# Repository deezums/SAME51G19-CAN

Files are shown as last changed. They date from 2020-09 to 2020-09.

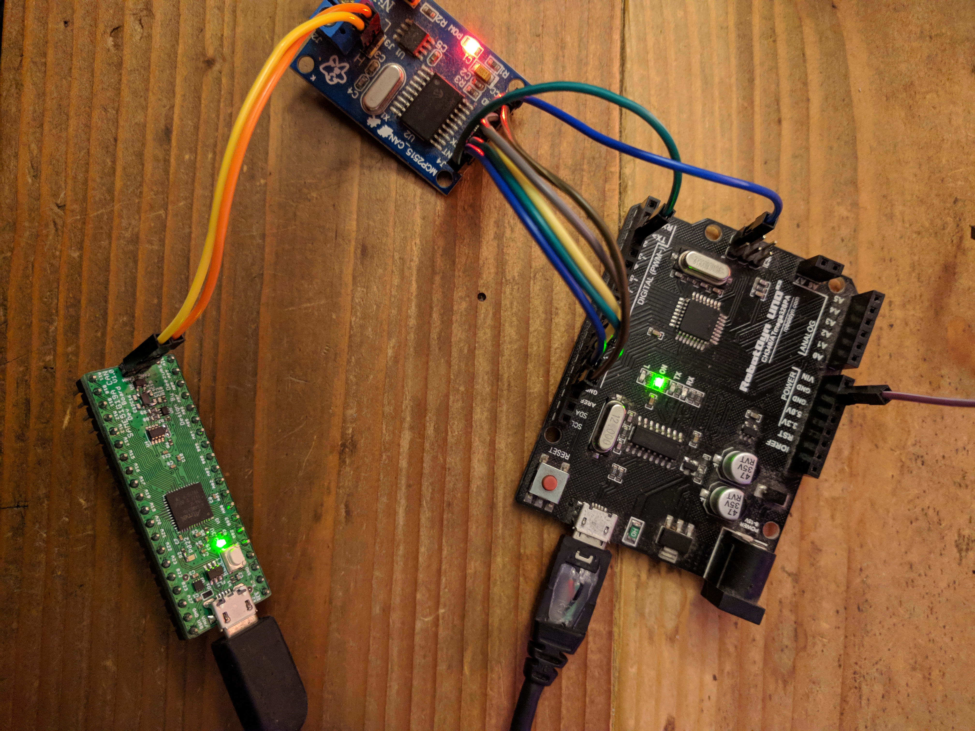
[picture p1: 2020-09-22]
extras/photos/SAME51G19A_CAN_INDEX.jpg

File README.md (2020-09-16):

# SAME51G19-CAN
Atmel ATSAME51G19A breakout board with TI TCAN33x transciever

This is version 1.0 of my ATSAME51G19A breakout board. 

Includes a 3.3V LDO, usb power, a led on PB22, reset switch, and 3V power led.

The canbus transiever contains a common mode choke, tvs array, and plenty of filter caps which can be optimally tuned to bus frequency. 

Digital split bus termiation using a mosfet array and resistors matched to rds, solder jumper allows disable, permanant pullup, or CPU control through PA21. 

Mostly 0402 components...

Tested working with atmel studio start examples and ATSAME54XPLAINED board. Hope to eventually port to Arduino with proper canbus library support.

Issues...

CMC pads should be narrowed vertically and can be horizontally compressed a fair bit.

Solder jumper pads are terrible, think too narrow and sharp. If not for 63/37 I don't think I could use them. 

TCAN33x, the extra function pins are not currently routed to CPU pins. Use TCAN332, or route the extra pins if you want to use hardware features of other variants.

Why did I make the silkscreen so small?! What pin is this!!

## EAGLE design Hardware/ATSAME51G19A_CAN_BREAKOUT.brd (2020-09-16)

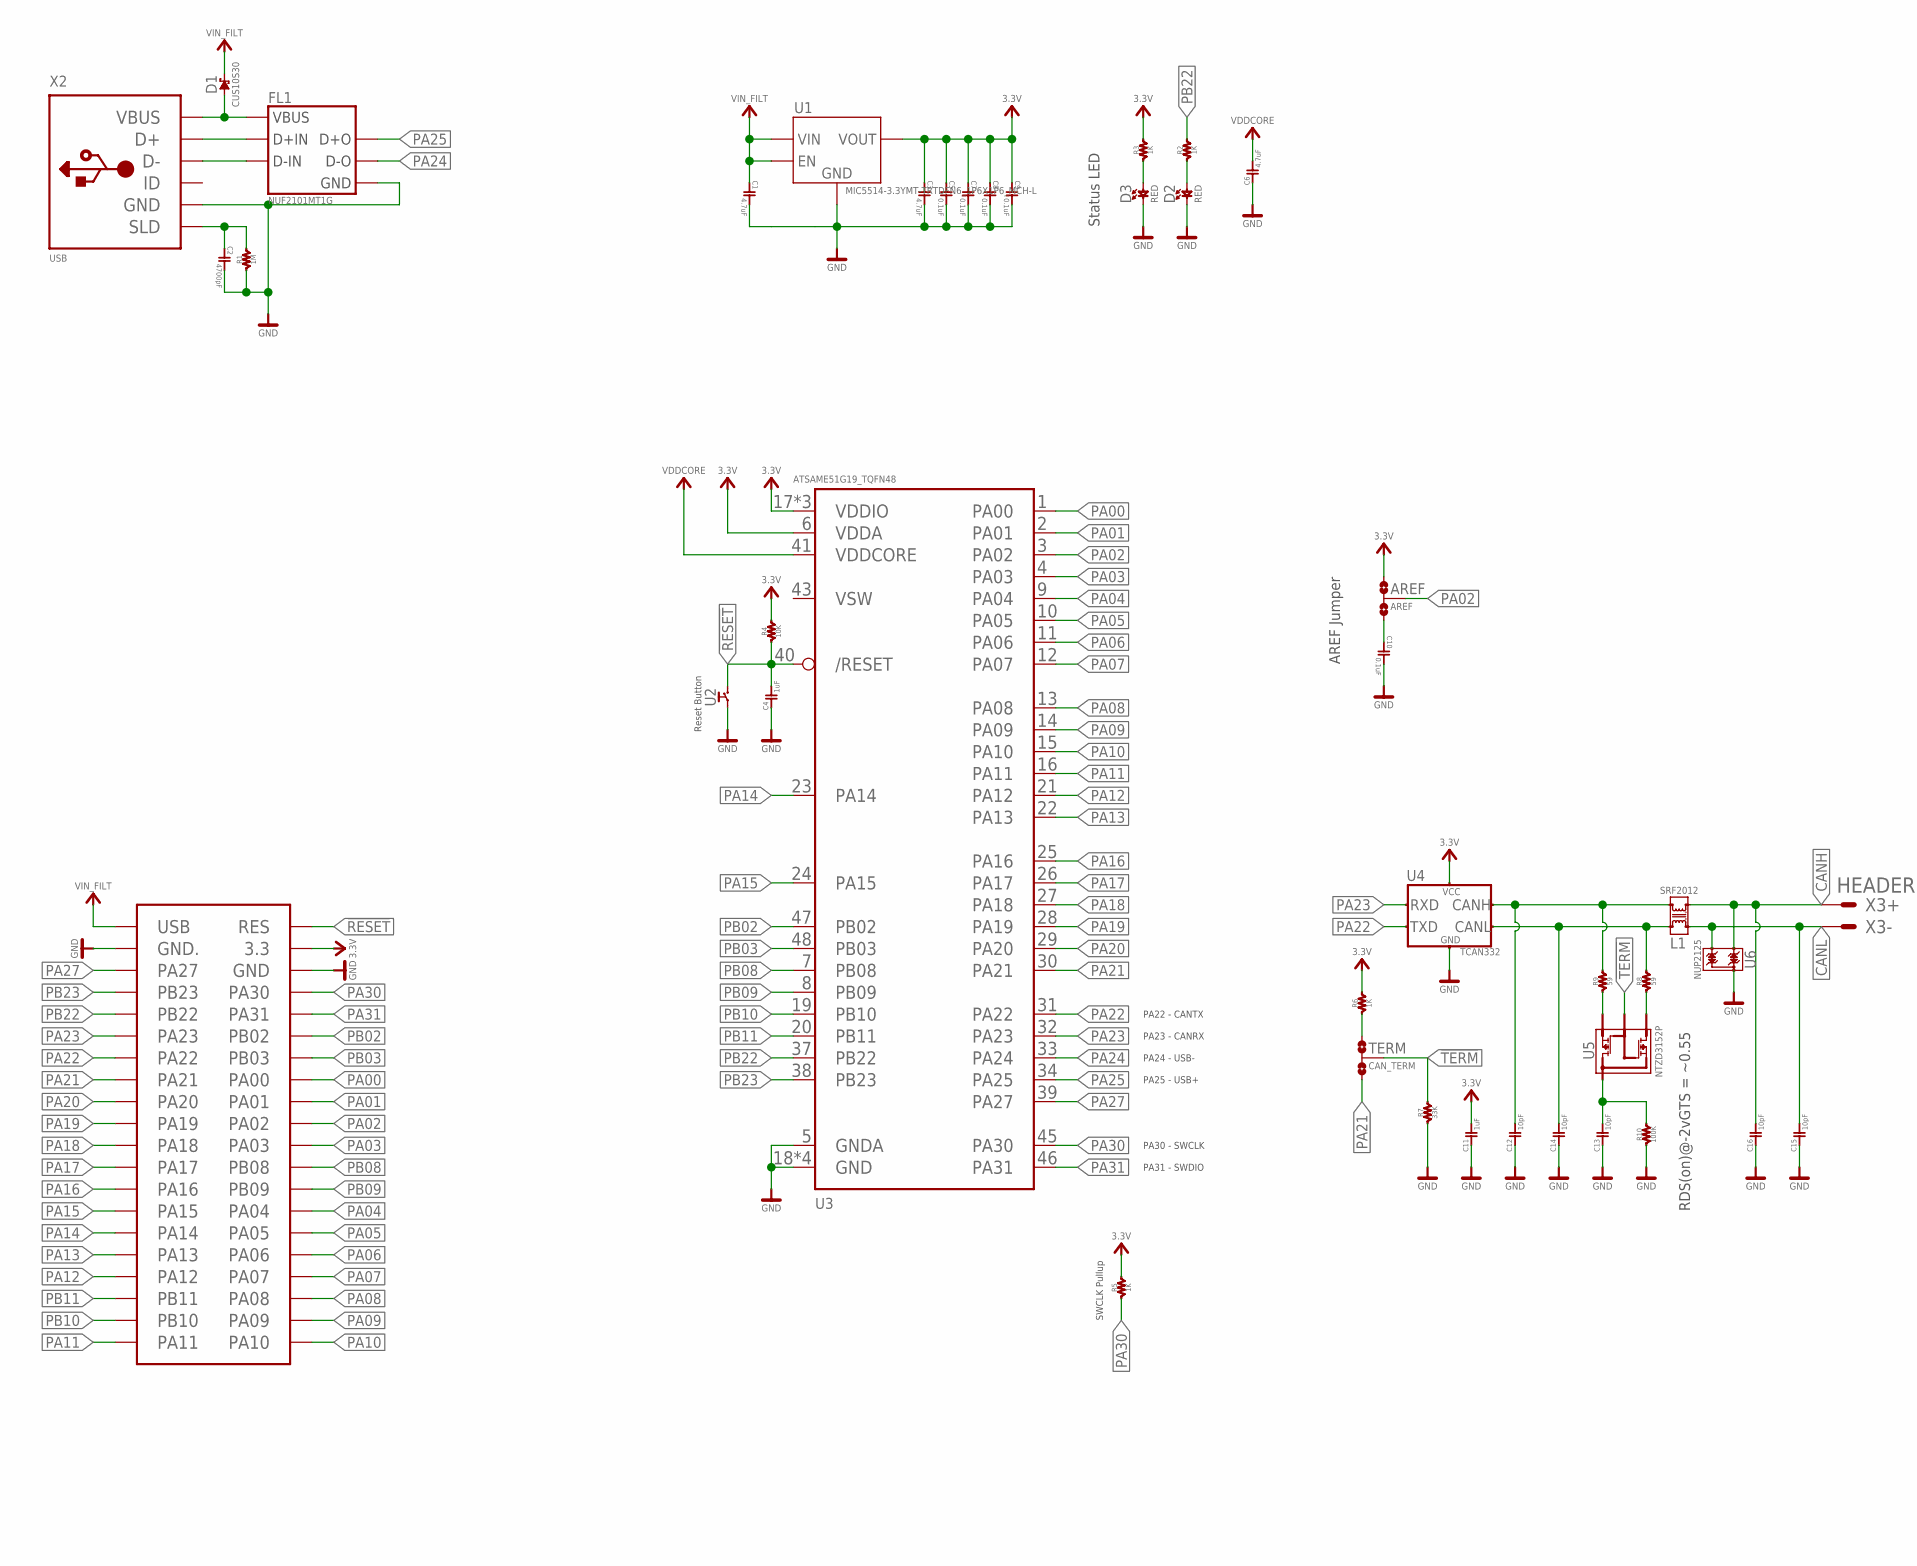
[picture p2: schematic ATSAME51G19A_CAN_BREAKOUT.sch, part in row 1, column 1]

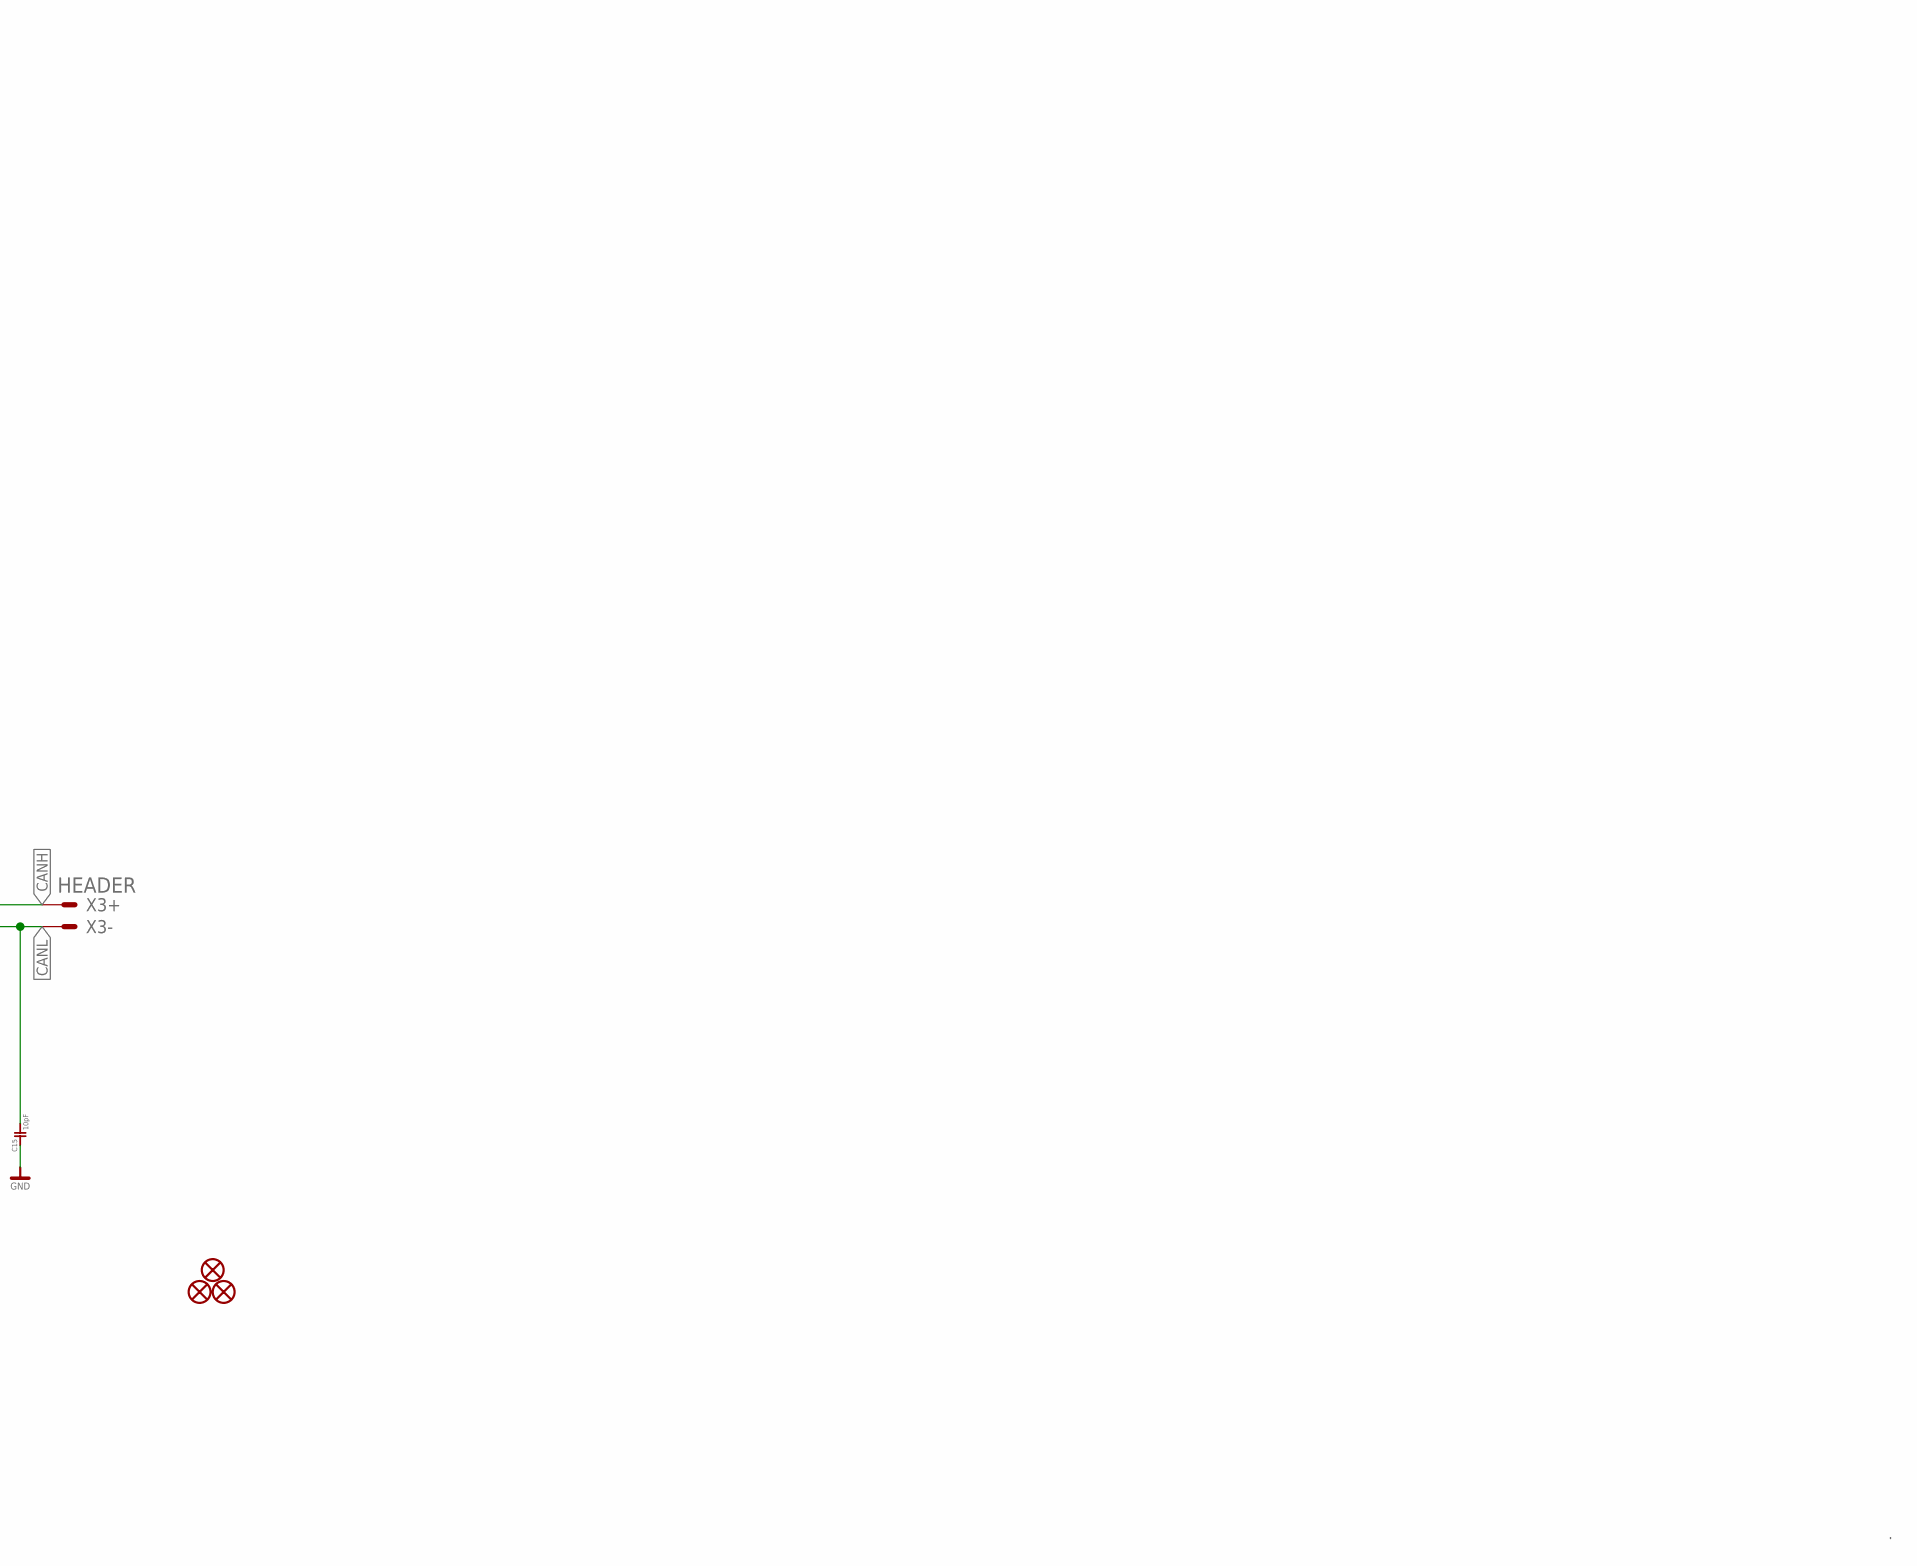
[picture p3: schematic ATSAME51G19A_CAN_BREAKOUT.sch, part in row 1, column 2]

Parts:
AREF: AREF; C0R-JMP
C1: 4.7uF; CAP0402; VOLTAGE 10V; MPN CL05A106MP8NUB8
C2: 4700pF; CAP0402; VOLTAGE 25V; MPN CC0402KRX7R8BB472
C3, C6: 4.7uF; CAP0402; VOLTAGE 6.3V; MPN GRM155R60J106ME05D
C4, C11: 1uF; CAP0402; VOLTAGE 6.3V; MPN CL05A105KQ5NNNC
C5, C7, C8, C9, C10: 0.1uF; CAP0402; VOLTAGE 6.3V; MPN CL05A105KQ5NNNC
C12, C13, C14, C15, C16: 10pF; CAP0402; VOLTAGE 50V; MPN C0402C100K5RAC7867
D1: CUS10S30; X3-WLB1608-2; MPN SDM2U30CSP-7
D2, D3: 0603 LED; LED-0603; MPN LNJ8W0C83RA
FID1, FID2, FID3: MICROBUILDER_FIDUCIAL_0.5MM
FL1: NUF2101MT1G; SOT95P275X110-6N
L1: SRF2012; SRF2012AA; MPN SRF2012-121YA
R1: 1M; RES0402; TOLERANCE 1%; MPN PFR05S-105-FNH
R2, R3: 1K; RES0402; TOLERANCE 1%; MPN CR0402-FX-1002GLF
R4: 10K; RES0402; TOLERANCE 1%; MPN CR0402-FX-1002GLF
R5, R6: 1K; RES0402; TOLERANCE 1%; MPN PFR05S-102-FNH
R7: 33K; RES0402; TOLERANCE 1%; MPN RMCF0402FT33K0
R8, R9: 59; RES0603; TOLERANCE 1%; MPN CRCW060359R0FKEAHP
R10: 100K; RES0402; TOLERANCE 1%; MPN CR0402-FX-1003GLF
TERM: CAN_TERM; C0R-JMP
U1: MIC5514-3.3YMT-TRTDFN6_1P6X1P6_MCH-L; TDFN6_1P6X1P6_MCH-L
U2: PUSH_SWITCHPTS815; SWITCH_PTS815; MPN PTS815 SJM 250 SMTR LFS
U3: ATSAME51G19_TQFN48; TQFN48_7MM; MPN ATSAME51G19A-MF
U4: TCAN332; DCN0008A; MPN TCAN332DCNR
U5: NTZD3152P; SOT-563; MPN NTZD3152PT1G
U6: NUP2125; SC70; MPN NUP2125WTT1G
X1: CONN; BOARDOUTLINE
X2: USB; 10118194
X3: HEADER; 22-23-2021

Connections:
3.3V: AREF.1, C3.1 (C1), C5.1 (C1), C7.1 (C1), C8.1 (C1), C9.1 (C1), C11.2 (C2), R3.2, R4.2, R5.2, R6.2, U1.4 (VOUT), U1.5 (VOUT), U3.6 (VDDA), U3.17 (VDDIO), U3.36 (VDDIO), U3.44 (VDDIO), U4.3 (VCC), X1.3.3
!RESET: C4.2 (C2), R4.1, U2.P$3 (2), U2.P$4 (2), U3.40 (/RESET), X1.!RES (RES)
!TERM: R7.2, TERM.2, U5.P$2 (GATE), U5.P$5 (GATE)
CANH: C16.2 (C2), L1.4, U6.1, X3.1
CANL: C15.2 (C2), L1.1, U6.2, X3.2
GND: C1.2 (C2), C2.2 (C2), C3.2 (C2), C4.1 (C1), C5.2 (C2), C6.1 (C1), C7.2 (C2), C8.2 (C2), C9.2 (C2), C10.2 (C2), C11.1 (C1), C12.1 (C1), C13.1 (C1), C14.1 (C1), C15.1 (C1), C16.1 (C1), D2.C, D3.C, FL1.2 (GND), R1.1, R7.1, R10.1, U1.6 (GND), U1.7 (GND), U2.P$1 (1), U2.P$2 (1), U3.5 (GNDA), U3.18 (GND), U3.35 (GND), U3.42 (GND), U3.THERMAL (GND), U4.2 (GND), U6.3, X1.GND, X1.GND., X2.5 (GND)
unnamed: C13.2 (C2), R10.2, U5.P$4 (DRAIN1), U5.P$6 (DRAIN1)
unnamed: R8.1, U5.P$3 (DRAIN2)
unnamed: D3.A, R3.1
unnamed: FL1.6 (D+I), X2.3 (D+)
unnamed: D2.A, R2.1
unnamed: FL1.4 (D-_I), X2.2 (D-)
unnamed: R6.1, TERM.1
unnamed: C2.1 (C1), R1.2, X2.GND4 (SLD), X2.GND5 (SLD), X2.P$1 (SLD), X2.P$2 (SLD), X2.P$3 (SLD), X2.P$4 (SLD)
unnamed: AREF.3, C10.1 (C1)
unnamed: C14.2 (C2), L1.2, R8.2, U4.6 (CANL)
unnamed: R9.1, U5.P$1 (SOURCE1)
unnamed: C12.2 (C2), L1.3, R9.2, U4.7 (CANH)
PA00: U3.1 (PA00), X1.PA00
PA01: U3.2 (PA01), X1.PA01
PA02: AREF.2, U3.3 (PA02), X1.PA02
PA03: U3.4 (PA03), X1.PA03
PA04: U3.9 (PA04), X1.PA04
PA05: U3.10 (PA05), X1.PA05
PA06: U3.11 (PA06), X1.PA06
PA07: U3.12 (PA07), X1.PA07
PA08: U3.13 (PA08), X1.PA08
PA09: U3.14 (PA09), X1.PA09
PA10: U3.15 (PA10), X1.PA10
PA11: U3.16 (PA11), X1.PA11
PA12: U3.21 (PA12), X1.PA12
PA13: U3.22 (PA13), X1.PA13
PA14: U3.23 (PA14), X1.PA14
PA15: U3.24 (PA15), X1.PA15
PA16: U3.25 (PA16), X1.PA16
PA17: U3.26 (PA17), X1.PA17
PA18: U3.27 (PA18), X1.PA18
PA19: U3.28 (PA19), X1.PA19
PA20: U3.29 (PA20), X1.PA20
PA21: TERM.3, U3.30 (PA21), X1.PA21
PA22: U3.31 (PA22), U4.1 (TXD), X1.PA22
PA23: U3.32 (PA23), U4.4 (RXD), X1.PA23
PA24: FL1.3 (D-_O), U3.33 (PA24)
PA25: FL1.1 (D+_O), U3.34 (PA25)
PA27: U3.39 (PA27), X1.PA27
PA30: R5.1, U3.45 (PA30), X1.PA30
PA31: U3.46 (PA31), X1.PA31
PB02: U3.47 (PB02), X1.PB02
PB03: U3.48 (PB03), X1.PB03
PB08: U3.7 (PB08), X1.PB08
PB09: U3.8 (PB09), X1.PB09
PB10: U3.19 (PB10), X1.PB10
PB11: U3.20 (PB11), X1.PB11
PB22: R2.2, U3.37 (PB22), X1.PB22
PB23: U3.38 (PB23), X1.PB23
VBUS: D1.ANNODE, FL1.5 (VBUS), X2.1 (VBUS)
VDDCORE: C6.2 (C2), U3.41 (VDDCORE)
VIN_FILT: C1.1 (C1), D1.CATHODE, U1.1 (EN), U1.2 (EN), U1.3 (VIN), X1.USB

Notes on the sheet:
PA25 - USB+
PA24 - USB-
PA23 - CANRX
PA22 - CANTX
PA30 - SWCLK
PA31 - SWDIO
Reset Button
SWCLK Pullup
AREF Jumper
Status LED
RDS(on)@-2vGTS = ~0.55

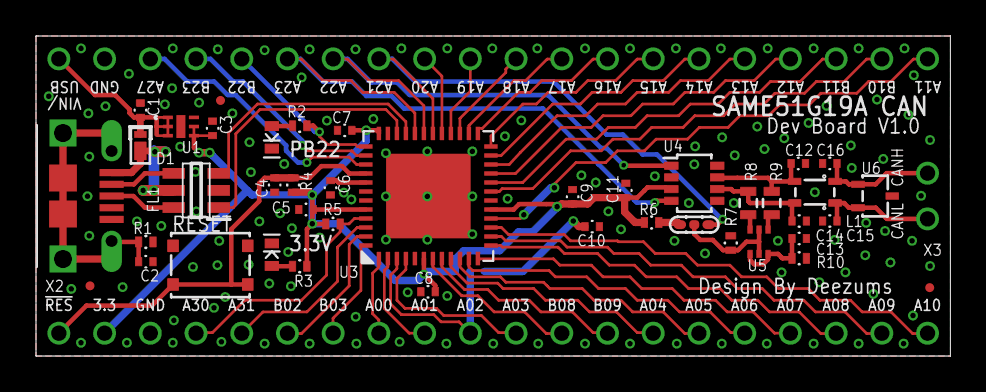
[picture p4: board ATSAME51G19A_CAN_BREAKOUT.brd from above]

Board: 2 copper layers, 50.8 x 17.8 mm, 45 parts (1 on the bottom side), 58 nets.

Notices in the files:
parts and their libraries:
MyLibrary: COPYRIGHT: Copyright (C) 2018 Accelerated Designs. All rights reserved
